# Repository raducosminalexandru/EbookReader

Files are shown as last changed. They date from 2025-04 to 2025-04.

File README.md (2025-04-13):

# OpenBook - E-book Reader Open-Source

In cadrul proiectului **OpenBook**, ne propunem sa revoluționam industria cititului digital prin dezvoltarea unui **e-book reader accesibil, eficient si open-source**. 🌍📚

Cu tehnologia de astazi, accesul la informatie este mai rapid ca niciodata, iar **OpenBook** isi propune sa ofere o solutie accesibila tuturor celor care doresc sa citeasca oriunde, oricand, fara a depinde de preturi exorbitante sau de platforme inchise. Suntem o echipa pasionata si inovativa, iar rolul nostru in acest proiect este sa creem un dispozitiv care sa ofere o experienta de citire excelenta si sa fie disponibil pentru toti utilizatorii, fara bariere. 💡

**OpenBook** este un e-book reader care va permite cititorilor sa acceseze si sa citeasca carti digitale intr-un mod simplu si eficient. Acesta ofera o solutie economica si open-source, ceea ce inseamna ca orice persoana va putea sa-l foloseasca, personalizeze sau imbunatateasca, fara restrictii legate de software sau costuri ridicate.

## Cum functioneaza

Prin utilizarea unor componente hardware eficiente si un software open-source, **OpenBook** va oferi o experienta de citire fluida, cu un design simplu si intuitiv. Acesta va suporta formate de carti populare si va fi usor de utilizat, chiar si pentru utilizatorii care nu sunt familiarizati cu tehnologia.

Prin intermediul acestui dispozitiv, punem bazele unui produs care va oferi cititorilor libertatea de a se bucura de carti digitale intr-un mod accesibil si fara compromisuri in ceea ce priveste performanta si functionalitatea.

## Bill of Materials (BOM) - varianta succinta a fisierului BOM

| Componenta | Link si Datasheet |
|---|---|
| **ESP32-C6-WROOM-1-N8** | [Mouser](https://eu.mouser.com/ProductDetail/Espressif-Systems/ESP32-C6-WROOM-1-N8?qs=8Wlm6%252BaMh8ST02Gmwp74cw%3D%3D) |
| **W25Q512JVEIQ** | [Mouser](https://eu.mouser.com/ProductDetail/Winbond/W25Q512JVEIQ?qs=l7cgNqFNU1jw6svr3at6tA%3D%3D) |
| **DS3231SN#** | [Mouser](https://www.mouser.ro/ProductDetail/100uF-Capacitor](https://eu.mouser.com/ProductDetail/Analog-Devices-Maxim-Integrated/DS3231SN?qs=1eQvB6Dk1vhUlr8%2FOrV0Fw%3D%3D)) |
| **FH34SRJ-24S-0.5SH** | [Mouser](https://www.mouser.ro/ProductDetail/Atmel/ATMEGA328P](https://eu.mouser.com/ProductDetail/Hirose-Connector/FH34SRJ-24S-0.5SH50?qs=iyLo5FA4poC8fzWlavnA7A%3D%3D)) |
| **USB4110-GF-A** | [Mouser](https://www.mouser.ro/ProductDetail/Atmel/ATMEGA328P](https://eu.mouser.com/ProductDetail/Hirose-Connector/FH34SRJ-24S-0.5SH50?qs=iyLo5FA4poC8fzWlavnA7A%3D%3D)](https://eu.mouser.com/ProductDetail/GCT/USB4110-GF-A?qs=KUoIvG%2F9IlYiZvIXQjyJeA%3D%3D)) |
| **BME680** | [Mouser](https://www.mouser.ro/ProductDetail/Atmel/ATMEGA328P](https://eu.mouser.com/ProductDetail/Hirose-Connector/FH34SRJ-24S-0.5SH50?qs=iyLo5FA4poC8fzWlavnA7A%3D%3D)](https://eu.mouser.com/ProductDetail/GCT/USB4110-GF-A?qs=KUoIvG%2F9IlYiZvIXQjyJeA%3D%3D)](https://eu.mouser.com/ProductDetail/Bosch-Sensortec/BME680?qs=v271MhAjFHjo0yA%2FC4OnDQ%3D%3D)) |
| **XC6220A331MR-G** | [Mouser](https://eu.mouser.com/ProductDetail/Torex-Semiconductor/XC6220A331MR-G?qs=AsjdqWjXhJ8ZSWznL1J0gg%3D%3D) |
| **USBLC6-2SC6Y** | [Mouser](https://ro.mouser.com/ProductDetail/STMicroelectronics/USBLC6-2SC6Y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) |
| **BD5229G-TR** | [Mouser](https://ro.mouser.com/ProductDetail/ROHM-Semiconductor/BD5229G-TR?qs=4kLU8WoGk0vvnhrrYwdszw%3D%3D) |
| **MAX17048G+T10** | [Mouser](https://ro.mouser.com/ProductDetail/Analog-Devices-Maxim-Integrated/MAX17048G%2bT10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) |
| **W25Q512JVEIQ** | [Mouser](https://ro.mouser.com/ProductDetail/ROHM-Semiconductor/BD5229G-TR?qs=4kLU8WoGk0vvnhrrYwdszw%3D%3D](https://ro.mouser.com/ProductDetail/Winbond/W25Q512JVEIQ?qs=l7cgNqFNU1jw6svr3at6tA%3D%3D))  
| **Qwiic Right Angle** | [Mouser](https://ro.mouser.com/ProductDetail/Adafruit/4208?qs=PzGy0jfpSMtbScLbr0L5dw%3D%3D) |

Urmatoarea imagine prezinta diagrama bloc de interconectare a componentelor, inclusiv tensiunile de alimentare si protocoalele de comunicatie utilizate intre ele. 🔌📡

<div align="center">

Diagrama

</div>

Modelul 3D al PCB-ului poate fi observat si in imaginea urmatoare, ceea ce permite o analiza detaliata a componentei si a configuratiei acestuia. Acest model ofera o perspectiva clara asupra dimensiunilor, plasarii componentelor si a traseelor de pe placa, ajutand la identificarea posibilelor interferente sau probleme de proiectare.

<div align="center">
  


</div>

Putem vizualiza si traseele mai bine in modelul 3D, ceea ce faciliteaza o analiza mai detaliata a conexiunilor dintre componente. Acest lucru permite identificarea eventualelor probleme legate de lungimea sau latimea traseelor, precum si a eventualelor puncte de coliziune sau interferenta.

<div align="center">
  


</div>

📐 **Integrarea modelului 3D al display-ului si al bateriei**

Pentru o reprezentare cat mai completa a ansamblului final, au fost incluse in proiect si modelele 3D ale display-ului si ale bateriei. Aceasta decizie a avut un rol esential in etapa de validare a designului, permitand o evaluare vizuala si functionala a intregului sistem, direct in mediul 3D.

Prin integrarea acestor componente, a fost posibila:
- ✅ **Verificarea compatibilitatii dimensionale** – Asigurarea ca fiecare componenta are un spatiu adecvat in interiorul carcasei, fara suprapuneri sau conflicte mecanice.
- 🧩 **Optimizarea pozitionarii componentelor** – Plasarea strategica a display-ului si bateriei pentru a facilita accesul, vizibilitatea, distributia greutatii si eficienta termica.
- 🧠 **Identificarea timpurie a potentialelor probleme de spatiu** – Vizualizarea in 3D permite observarea oricaror interferente sau nepotriviri intre PCB, baterie, display si carcasa proiectului.
- 🔧 **Eficientizarea procesului de prototipare** – Un model 3D complet si realist reduce riscul de erori in faza de fabricatie, scurtand ciclurile de testare si ajustare.

Aceasta abordare contribuie direct la cresterea fiabilitatii produsului final, asigurand ca toate componentele nu doar functioneaza impreuna, ci si se potrivesc perfect in structura fizica a dispozitivului.

</div>

<div align="center">
  


</div>

<div align="center">
  


</div>

<div align="center">
  
3D EBOOK

</div>

### Cerinte de 'Good Practice' respectate de dispozitiv:

✅ Traseele de alimentare (VCC, VUSB, VBUS, 3V3 etc.) sunt rutate folosind width = 0.3mm, semnalele de date cu minimum width de 0.15mm.  
✅ Antena modulului ESP32 este amplasata spre exteriorul PCB-ului si PCB-ul trebuie sa fie decupat sub antena.  
✅ Verificare ERC si DRC.  
✅ Condensatoarele de decuplare (100nF) sunt amplasate cat mai aproape de pinii de alimentare ai diferitelor module si circuite integrate.  
✅ Suprafata PCB-ului de sub antena modulului ESP32 a fost decupata pentru a crea cat mai putine interferente cu semnalul radio.  
✅ Planuri de masa situate pe ambele nivele (TOP, BOTTOM).  
✅ Antena modulului ESP32 este amplasata spre exteriorul PCB-ului si PCB-ul este decupat sub antena.  
✅ S-a aplicat 'Via Stitching' intre cele doua planuri de masa, in special in preajma modulului ESP32, precum si in jurul componentelor principale.
✅ Placa are grosimea de 1mm, lucru ce permite introducerea in carcasa si pozitionarea corecta a mufelor.
✅ Vias-uri legate de masa au fost aplicate in toate zonele in care nu se facea 'Pour'.
✅ Valorile rezistentelor si condensatoarelor au fost sterse din 'Board' de pe layer-ul 'Silkscreen' pentru a permite o lizibilitate mai buna.
✅ Footprint-urile anumitor componente au fost schimbate prin modificarea marimilor unor pini, permitand traseele de putere sa se lege la ele, acestea fiind mai groase.
✅ Nu exista unghiuri drepte in cadrul rutarii pe placa.

### Erori acceptate pe dispozitiv:
✅Erorile 'Board Outline Clearance', conform cerintelor impuse.

### 🌐 Surse auxiliare utilizate pentru modele 3D

## Surse externe pentru modelarea 3D a ansamblului

Pentru a completa designul 3D al placii si a asigura o reprezentare cat mai fidela a ansamblului, au fost utilizate urmatoarele surse externe:

🔍 **Component Search Engine**  
Aceasta platforma a fost principalul instrument folosit pentru importarea modelelor 3D ale componentelor electronice standard. A oferit o integrare rapida si precisa cu software-ul de proiectare, facilitand plasarea corecta a componentelor in layout-ul 3D.

🟢 **Farnell**  
Modelele 3D ale butoanelor nu erau disponibile in Component Search Engine, asa ca s-a apelat la biblioteca pusa la dispozitie de Farnell. Aceasta ofera fisiere 3D compatibile si bine detaliate, utile pentru verificarea dimensiunilor fizice si a spatiului ocupat pe placa.

📦 **GrabCAD**  
Modelul 3D al Solder Jumper-ului (SJ) a fost descarcat de pe GrabCAD, o platforma colaborativa care pune la dispozitie o varietate larga de modele CAD. A fost ales un model potrivit, care a fost ulterior ajustat pentru a corespunde dimensiunilor reale folosite in proiect.

# Pinii ESP32 C6 folositi

Se poate vizualiza modul de conectare al componentelor in raport cu ESP32 C6. Se poate observa clar cum acesta poate fi atat 'Master', cat si 'Slave', lucru ce permite comunicatia SPI.

## 1. SD Card
- **CLK** → GPIO6  
- **CMD** → GPIO7  
- **DATA0** → GPIO8  
- **DATA1** → GPIO9  
- **DATA2** → GPIO10  
- **DATA3** → GPIO11  

## 2. Ecran E-Paper
Comunicare prin SPI și GPIO-uri adiționale:
- **MOSI** → GPIO4  
- **SCK** → GPIO5  
- **DC** → GPIO18  
- **CS** → GPIO17  
- **BUSY** → GPIO16  
- **RESET** → GPIO15  

## 3. Memorie NOR Flash 64MB (W25Q512JV)
Comunicare prin SPI:
- **MOSI** → GPIO4  
- **MISO** → GPIO3  
- **CLK** → GPIO5  
- **CS** → GPIO2  

## 4. Senzor de mediu BME688 (I2C)
- **SCL** → GPIO20  
- **SDA** → GPIO19  

## 5. RTC DS3231SN (I2C)
- **SCL** → GPIO20  
- **SDA** → GPIO19  

## 6. Qwiic / Stemma QT (I2C)
- **SCL** → GPIO20  
- **SDA** → GPIO19  

## 7. Indicator nivel baterie (MAX17048G+T10) (I2C)
- **SCL** → GPIO20  
- **SDA** → GPIO19  

## 8. Buton de Reset și Boot
- **Reset** → GPIO0  
- **Boot** → GPIO1

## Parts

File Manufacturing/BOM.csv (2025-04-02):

Qty | Value | Device | Package | Parts | Description | ARROW_PART_NUMBER | ARROW_PRICE-STOCK | AVAILABILITY | CENTROID_NOT_SPECIFIED | CHECK_PRICES | COPYRIGHT | DATASHEET | DESCRIPTION | DIGIKEY_DESCRIPTION | DIGIKEY_PART_NUMBER | HEIGHT | LEAD_FREE | MANUFACTURER_NAME | MANUFACTURER_PART_NUMBER | MF | MFR_NAME | MOUSER_PART_NUMBER | MOUSER_PRICE-STOCK | MOUSER_TESTING_PART_NUMBER | MOUSER_TESTING_PRICE-STOCK | MP | MPN | PACKAGE | POPULARITY | PREFIX | PRICE | PROD_ID | PURCHASE-URL | ROHS | SNAPEDA_LINK | SPICEMODEL | SPICEPREFIX | TEMPERATURE_RANGE_HIGH | TEMPERATURE_RANGE_LOW | TP_SIGNAL_NAME | VALUE
1 |  | ADAFRUIT_LEDCHIP-LED0603 | ADAFRUIT_CHIP-LED0603 | CHG_LED | LED
2 |  | ESP32_WROVER_EAGLE-LTSPICE_CC0402 | ESP32_WROVER_EAGLE-LTSPICE_C0402 | C4_USB, C5_USB | CAPACITOR, European symbol |  |  |  |  |  |  |  |  |  |  |  |  |  |  |  |  |  |  |  |  |  |  |  |  |  |  |  |  |  |  | NONE | C
1 |  | SJ | SJ | SJ1 | SMD solder JUMPER |  |  |  |  |  |  |  |  |  |  |  |  |  |  |  |  |  |  |  |  |  |  |  | 3
1 | 0.1uF/50V | ESP32_WROVER_EAGLE-LTSPICE_CC0402 | ESP32_WROVER_EAGLE-LTSPICE_C0402 | EPD_C5 | CAPACITOR, European symbol |  |  |  |  |  |  |  |  |  |  |  |  |  |  |  |  |  |  |  |  |  |  |  |  |  |  |  |  |  |  | NONE | C
1 | 0.47 | ESP32_WROVER_EAGLE-LTSPICE_RR0402 | ESP32_WROVER_EAGLE-LTSPICE_R0402 | R3 | RESISTOR, European symbol |  |  |  |  |  |  |  |  |  |  |  |  |  |  |  |  |  |  |  |  |  |  |  |  |  |  |  |  |  |  | NONE | R
1 | 100K | ESP32_WROVER_EAGLE-LTSPICE_RR0402 | ESP32_WROVER_EAGLE-LTSPICE_R0402 | R1_PWRUSB | RESISTOR, European symbol |  |  |  |  |  |  |  |  |  |  |  |  |  |  |  |  |  |  |  |  |  |  |  |  |  |  |  |  |  |  | NONE | R
7 | 100nF | ESP32_WROVER_EAGLE-LTSPICE_CC0402 | ESP32_WROVER_EAGLE-LTSPICE_C0402 | C1, C2, C6, C9, C10, C11, C_DELAY | CAPACITOR, European symbol |  |  |  |  |  |  |  |  |  |  |  |  |  |  |  |  |  |  |  |  |  |  |  |  |  |  |  |  |  |  | NONE | C
1 | 100uF | RCL_CPOL-EUCT3528 | RCL_CT3528 | C3 | POLARIZED CAPACITOR, European symbol |  |  |  |  |  |  |  |  |  |  |  |  |  |  |  |  |  |  |  |  |  |  |  | 0 |  |  |  |  |  |  |  | C
16 | 10K | ESP32_WROVER_EAGLE-LTSPICE_RR0402 | ESP32_WROVER_EAGLE-LTSPICE_R0402 | R1, R1-PINH1, R1_PINH, R2-PINH1, R2_PINH, R4, R5, R6, R7, R8, R9, R10, R_BOOT, R_CHANGE, R_CL1, R_RESET | RESISTOR, European symbol |  |  |  |  |  |  |  |  |  |  |  |  |  |  |  |  |  |  |  |  |  |  |  |  |  |  |  |  |  |  | NONE | R
2 | 10uF | ESP32_WROVER_EAGLE-LTSPICE_CC0402 | ESP32_WROVER_EAGLE-LTSPICE_C0402 | C5, C7 | CAPACITOR, European symbol |  |  |  |  |  |  |  |  |  |  |  |  |  |  |  |  |  |  |  |  |  |  |  |  |  |  |  |  |  |  | NONE | C
1 | 112A-TAAR-R03_ATTEND | 112A-TAAR-R03_ATTEND | 112ATAARR03ATTEND | J4 | Micro SD Card Socket, Push-Push Type, Top Mount, SMT, H=1.83mm, 10u |  |  |  |  |  |  |  | Micro SD Card Socket | Push-Push Type | Top Mount | SMT | H=1.83mm | 10u |  |  | 1.9mm |  | ATTEND | 112A-TAAR-R03 ATTEND
1 | 15 | ESP32_WROVER_EAGLE-LTSPICE_RR0402 | ESP32_WROVER_EAGLE-LTSPICE_R0402 | R_CAPACITOR | RESISTOR, European symbol |  |  |  |  |  |  |  |  |  |  |  |  |  |  |  |  |  |  |  |  |  |  |  |  |  |  |  |  |  |  | NONE | R
9 | 1uF/50V | ESP32_WROVER_EAGLE-LTSPICE_CC0402 | ESP32_WROVER_EAGLE-LTSPICE_C0402 | EPD_C1, EPD_C2, EPD_C6, EPD_C7, EPD_C8, EPD_C9, EPD_C10, EPD_C11, EPD_C12 | CAPACITOR, European symbol |  |  |  |  |  |  |  |  |  |  |  |  |  |  |  |  |  |  |  |  |  |  |  |  |  |  |  |  |  |  | NONE | C
1 | 2.2 | ESP32_WROVER_EAGLE-LTSPICE_RR0402 | ESP32_WROVER_EAGLE-LTSPICE_R0402 | R2 | RESISTOR, European symbol |  |  |  |  |  |  |  |  |  |  |  |  |  |  |  |  |  |  |  |  |  |  |  |  |  |  |  |  |  |  | NONE | R
1 | 200 | ESP32_WROVER_EAGLE-LTSPICE_RR0402 | ESP32_WROVER_EAGLE-LTSPICE_R0402 | R1_BAT | RESISTOR, European symbol |  |  |  |  |  |  |  |  |  |  |  |  |  |  |  |  |  |  |  |  |  |  |  |  |  |  |  |  |  |  | NONE | R
2 | 20V/4.2A/52mO/1.4W | ESP32_WROVER_SPARKFUN-DISCRETESEMI_MOSFET_PCH-DMG2305UX-7 | ESP32_WROVER_SPARKFUN-DISCRETESEMI_SOT23-3 | Q1, Q2 | P-channel MOSFETs |  |  |  |  |  |  |  |  |  |  |  |  |  |  |  |  |  |  |  |  |  |  |  |  |  |  | TRAN-14388 |  |  |  |  |  |  |  |  | 20V/4.2A/52mO/1.4W
1 | 2K | ESP32_WROVER_EAGLE-LTSPICE_RR0402 | ESP32_WROVER_EAGLE-LTSPICE_R0402 | R2_BAT | RESISTOR, European symbol |  |  |  |  |  |  |  |  |  |  |  |  |  |  |  |  |  |  |  |  |  |  |  |  |  |  |  |  |  |  | NONE | R
4 | 4.7uF | ESP32_WROVER_EAGLE-LTSPICE_CC0402 | ESP32_WROVER_EAGLE-LTSPICE_C0402 | C1_BAT, C1_BAT1, C1_BAT2, C2_BAT | CAPACITOR, European symbol |  |  |  |  |  |  |  |  |  |  |  |  |  |  |  |  |  |  |  |  |  |  |  |  |  |  |  |  |  |  | NONE | C
1 | 4.7uF/25V | ESP32_WROVER_EAGLE-LTSPICE_CC0402 | ESP32_WROVER_EAGLE-LTSPICE_C0402 | C4 | CAPACITOR, European symbol |  |  |  |  |  |  |  |  |  |  |  |  |  |  |  |  |  |  |  |  |  |  |  |  |  |  |  |  |  |  | NONE | C
2 | 5k1 | ESP32_WROVER_EAGLE-LTSPICE_RR0402 | ESP32_WROVER_EAGLE-LTSPICE_R0402 | R2-USB, R2-USB1 | RESISTOR, European symbol |  |  |  |  |  |  |  |  |  |  |  |  |  |  |  |  |  |  |  |  |  |  |  |  |  |  |  |  |  |  | NONE | R
1 | 68uH | 744043680IND_4828-WE-TPC_WRE | IND_4828-WE-TPC_WRE | L1 |  |  |  |  |  |  | Copyright (C) 2024 Ultra Librarian. All rights reserved. |  |  |  |  |  |  |  | 744043680 |  | Wurth Electronics
1 | BD5229G-TR | BD5229G-TR | SOT95P280X125-5N | IC1 | Voltage Detector with Adjustable Delay Time: CMOS processes are utilized to develop high precision, low current consumption CMOS reset ICs that allow arbitrary setting of the delay time. The extensive lineup includes both Nch Open Drain and CMOS output types in a wide range of detection voltages (from 2.3V to 6.0V, in 0.1V steps), enabling selection of the ideal solution based on customer requirements. In addition, the entire series is of course both lead-free and RoHS-compliant. |  |  |  |  |  |  |  | Voltage Detector with Adjustable Delay Time: CMOS processes are utilized to develop high precision | low current consumption CMOS reset ICs that allow arbitrary setting of the delay time. The extensive lineup includes both Nch Open Drain and CMOS output types in a wide range of detection voltages (from 2.3V to 6.0V | in 0.1V steps) | enabling selection of the ideal solution based on customer requirements. In addition | the entire series is of course both lead-free and RoHS-compliant. |  |  | 1.25mm |  | ROHM Semiconductor | BD5229G-TR |  |  | 755-BD5229G-TR | https://www.mouser.co.uk/ProductDetail/ROHM-Semiconductor/BD5229G-TR?qs=4kLU8WoGk0vvnhrrYwdszw%3D%3D
3 | BUTTON_CUSYOMV1 | BUTTON_CUSYOMV1 | MYBUTTON | BOOT_BUTTON, CHANGE_BUTTON, RESET_BUTTON
1 | CPH3225A | CPH3225A | CAPCP3225X100N | C10_SUPERCAP | Cap 0.011F 3.3V 1210 Flat Check availability |  |  | Not in stock |  | https://www.snapeda.com/parts/CPH3225A/Seiko+Instruments/view-part/?ref=eda |  |  | 11 mF (EDLC) Supercapacitor 3.3 V 1210 (3225 Metric) - - |  |  |  |  |  |  | Seiko Instruments |  |  |  |  |  | CPH3225A |  | 1210 Seiko |  |  | None |  | https://www.snapeda.com/api/url_track_click_mouser/?unipart_id=562593&manufacturer=Seiko Instruments&part_name=CPH3225A&search_term=None |  | https://www.snapeda.com/parts/CPH3225A/Seiko+Instruments/view-part/?ref=snap
1 | DS3231SN# | DS3231SN# | SOIC127P1032X265-16N | U3 | Real Time Clock Serial 16-Pin SOIC W T/R Check availability |  |  | In Stock |  | https://www.snapeda.com/parts/DS3231SN%23/Analog+Devices/view-part/?ref=eda |  |  | Extremely Accurate I²C-Integrated RTC/TCXO/Crystal |  |  |  |  |  |  | Analog Devices |  |  |  |  |  | DS3231SN# |  | SOIC-16 Maxim |  |  | None |  | https://www.snapeda.com/api/url_track_click_mouser/?unipart_id=99048&manufacturer=Analog Devices&part_name=DS3231SN#&search_term=None |  | https://www.snapeda.com/parts/DS3231SN%23/Analog+Devices/view-part/?ref=snap
1 | ESP32-C6-WROOM-1-N8 | ESP32-C6-WROOM-1-N8 | XCVR_ESP32-C6-WROOM-1-N8 | U2 | Check availability |  |  | In Stock |  | https://www.snapeda.com/parts/ESP32-C6-WROOM-1-N8/Espressif+Systems/view-part/?ref=eda |  |  | Multiprotocol Modules ESP32-C6 module | Wi-Fi 6 in 2.4 GHz band | Bluetooth 5 | Zigbee 3.0 and Thread. ESP34-WROOM Compatible - ENGINEERING SAMPLE |  |  |  |  |  |  | Espressif Systems |  |  |  |  |  | ESP32-C6-WROOM-1-N8 |  | None |  |  | None |  |  |  | https://www.snapeda.com/parts/ESP32-C6-WROOM-1-N8/Espressif+Systems/view-part/?ref=snap
1 | ESP32C6_VARISTORCN1812 | ESP32C6_VARISTORCN1812 | ESP32C6_VARISTOR_CT/CN1812 | PFMF.050.1 | VARISTOR |  |  |  |  |  |  |  |  |  |  |  |  |  |  |  |  |  |  |  |  |  |  |  | 0
2 | ESP32_WROVER_AVX---SD0805S020S1R0_AVX_SD0805S020S1R0_0_0AVX_SD0805S020S1R0_0_0 | ESP32_WROVER_AVX---SD0805S020S1R0_AVX_SD0805S020S1R0_0_0AVX_SD0805S020S1R0_0_0 | ESP32_WROVER_AVX---SD0805S020S1R0_AVX_SD0805S020S1R0_0 | D2, D7 | Schottky Barrier Rectifier Diode |  |  |  | No |  |  | http://datasheets.avx.com/schottky.pdf |  | DIODE SCHOTTKY 20V 1A 0805 | 478-7800-1-ND |  | yes |  |  | AVX |  | 581-SD0805S020S1R0 |  |  |  |  |  | 0805 (2012 metric) |  | D |  |  |  | yes |  |  |  | +125°C | -55°C
1 | ESP32_WROVER_BME680_BME680 | ESP32_WROVER_BME680_BME680 | ESP32_WROVER_BME680_PSON80P300X300X100-8N | SENSOR2 | Integrated Environmental Unit |  |  | Unavailable |  |  |  |  | Integrated Environmental Unit |  |  |  |  |  |  | Bosch Sensortec |  |  |  |  |  | BME680 |  | LGA-8 Bosch Tools |  |  | None
1 | ESP32_WROVER_SPARKFUN-IC-POWER_MCP73831 | ESP32_WROVER_SPARKFUN-IC-POWER_MCP73831 | ESP32_WROVER_SPARKFUN-IC-POWER_SOT23-5 | MCP73831 | MCP73831T Li-Ion, Li-Pol Controller |  |  |  |  |  |  |  |  |  |  |  |  |  |  |  |  |  |  |  |  |  |  |  |  |  |  | IC-09995
1 | FH34SRJ-24S-0.5SH_99_ | FH34SRJ-24S-0.5SH_99_ | FH34SRJ24S05SH99 | J1 | (0.50mm) Surface Mount, Right Angle |  |  |  |  |  |  |  | 24 Position FFC | FPC Connector Contacts | (0.50mm) Surface Mount | Right Angle |  |  | 1.1mm |  | Hirose | FH34SRJ-24S-0.5SH(99) |  |  | 798-FH34SRJ24S05SH99 | https://www.mouser.co.uk/ProductDetail/Hirose-Connector/FH34SRJ-24S-0.5SH99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
1 | MAX17048G+T10 | MAX17048G+T10 | SON50P200X200X80-9N | U4 | Check availability |  |  | In Stock |  | https://www.snapeda.com/parts/MAX17048G+T10/Analog+Devices/view-part/?ref=eda |  |  | 3µA 1-Cell/2-Cell Fuel Gauge with ModelGauge |  |  |  |  |  |  | Analog Devices |  |  |  |  |  | MAX17048G+T10 |  | TDFN-8 Maxim |  |  | None |  | https://www.snapeda.com/api/url_track_click_mouser/?unipart_id=329239&manufacturer=Analog Devices&part_name=MAX17048G+T10&search_term=None |  | https://www.snapeda.com/parts/MAX17048G+T10/Analog+Devices/view-part/?ref=snap
3 | MBR0530 | MBR0530 | SOD3716X135N | D3, D4, D5 | ON SEMICONDUCTOR - MBR0530 - DIODE, SCHOTTKY, 0.5A, 30V, SOD-123 |  |  | In Stock |  | https://www.snapeda.com/parts/MBR0530/Onsemi/view-part/?ref=eda |  |  | Diode Schottky 30 V 500mA Surface Mount SOD-123 |  |  |  |  |  |  | ON Semiconductor |  |  |  |  |  | MBR0530 |  | SOD-123-2 ON Semiconductor |  |  | None |  | https://www.snapeda.com/api/url_track_click_mouser/?unipart_id=179458&manufacturer=ON Semiconductor&part_name=MBR0530&search_term=None |  | https://www.snapeda.com/parts/MBR0530/Onsemi/view-part/?ref=snap
6 | PGB1010603MR | PGB1010603MR | DIOC1608X36N | D6, D8, D9, D10, D11, D12 | Check availability |  |  | In Stock |  | https://www.snapeda.com/parts/PGB1010603MR/Littelfuse/view-part/?ref=eda |  |  | 150V (Typ) Clamp - Ipp Tvs Diode Surface Mount 0603 (1608 Metric) |  |  |  |  |  |  | Littelfuse Inc. |  |  |  |  |  | PGB1010603MR |  | 0603 Littelfuse Inc. |  |  | None |  | https://www.snapeda.com/api/url_track_click_mouser/?unipart_id=5659453&manufacturer=Littelfuse Inc.&part_name=PGB1010603MR&search_term=None |  | https://www.snapeda.com/parts/PGB1010603MR/Littelfuse/view-part/?ref=snap
1 | QWIIC_RIGHT_ANGLE | QWIIC_CONNECTORJS-1MM | JST04_1MM_RA | J3 | SparkFun I2C Standard Qwiic Connector |  |  |  |  |  |  |  |  |  |  |  |  |  |  |  |  |  |  |  |  |  |  |  |  |  |  | CONN-13694 |  |  |  |  |  |  |  |  | QWIIC_RIGHT_ANGLE
1 | SAMACSYS_PARTS_USB4110-GF-A | SAMACSYS_PARTS_USB4110-GF-A | SAMACSYS_PARTS_USB4110GFA | J2 | CONN USB 2.0 TYPE-C R/A SMT |  |  |  |  |  |  |  | CONN USB 2.0 TYPE-C R/A SMT |  |  | 3.26mm |  | GCT (GLOBAL CONNECTOR TECHNOLOGY) | USB4110-GF-A |  |  | 640-USB4110-GF-A | https://www.mouser.co.uk/ProductDetail/GCT/USB4110-GF-A?qs=KUoIvG%2F9IlYiZvIXQjyJeA%3D%3D
1 | SI1308EDL-T1-GE3 | SI1308EDL-T1-GE3 | SOT65P210X110-3N | Q3 | MOSFET N-Ch 30V 1.5A TrenchFET SC70 Vishay Si1308EDL-T1-GE3 N-channel MOSFET Transistor, 1.5 A, 30 V, 3-Pin SC-70 |  |  | In Stock |  | https://www.snapeda.com/parts/SI1308EDL-T1-GE3/Vishay+Siliconix/view-part/?ref=eda |  |  | Si1308EDL-T1-GE3 N-channel MOSFET Transistor | 1.5 A | 30 V | 3-Pin SC-70 | Siliconix / Vishay SI1308EDL-T1-GE3 |  |  |  |  |  |  | Vishay Siliconix |  |  |  |  |  | SI1308EDL-T1-GE3 |  | SOT-323 Vishay Semiconductor |  |  | None |  | https://www.snapeda.com/api/url_track_click_mouser/?unipart_id=274603&manufacturer=Vishay Siliconix&part_name=SI1308EDL-T1-GE3&search_term=None |  | https://www.snapeda.com/parts/SI1308EDL-T1-GE3/Vishay+Siliconix/view-part/?ref=snap
17 | TPTP20R | TPTP20R | TP20R | TP1, TP2, TP3, TP4, TP5, TP6, TP7, TP8, TP9, TP10, TP11, TP12, TP13, TP14, TP15, TP16, TP17 | Test pad |  |  |  |  |  |  |  |  |  |  |  |  |  |  |  |  |  |  |  |  |  |  |  | 2
1 | USBLC6-2SC6Y | USBLC6-2SC6Y | SOT95P280X145-6N | D1 | Low Cap. ESD Protection Auto SOT-23-6 STMicroelectronics USBLC6-2SC6Y, Dual Uni-Directional TVS Diode Array, 6-Pin SOT-23 |  |  | In Stock |  | https://www.snapeda.com/parts/USBLC6-2SC6Y/STMicroelectronics/view-part/?ref=eda |  |  | 17V Clamp 5A (8/20µs) Ipp Tvs Diode Surface Mount SOT-23-6 |  |  |  |  |  |  | STMicroelectronics |  |  |  |  |  | USBLC6-2SC6Y |  | SOT-23-6 STMicroelectronics |  |  | None |  |  |  | https://www.snapeda.com/parts/USBLC6-2SC6Y/STMicroelectronics/view-part/?ref=snap
1 | W25Q512JVEIQ | W25Q512JVEIQ | SON127P600X800X80-9N | U1 | Check availability |  |  | In Stock |  | https://www.snapeda.com/parts/W25Q512JVEIQ/Winbond+Electronics/view-part/?ref=eda |  |  | FLASH - NOR Memory IC 512Mb (64M x 8) SPI - Quad I/O 133 MHz 8-WSON (8x6) |  |  |  |  |  |  | Winbond Electronics |  |  |  |  |  | W25Q512JVEIQ |  | Package |  |  | None |  |  |  | https://www.snapeda.com/parts/W25Q512JVEIQ/Winbond+Electronics/view-part/?ref=snap
1 | XC6220A331MR-G | XC6220A331MR-G | SOT95P280X120-5N | IC4 | LDO Voltage Regulators |  |  |  |  |  |  |  | LDO Voltage Regulators |  |  | 1.2mm |  | Torex | XC6220A331MR-G |  |  | 865-XC6220A331MR-G | https://www.mouser.co.uk/ProductDetail/Torex-Semiconductor/XC6220A331MR-G?qs=AsjdqWjXhJ8ZSWznL1J0gg%3D%3D

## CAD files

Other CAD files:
Mechanical/EbookReader PCB 3D.step
Mechanical/OpenBook Enclosure.step

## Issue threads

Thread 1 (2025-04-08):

Diagrama bloc

mariapana, 2025-04-08:
Pentru a putea vedea mai usor conexiunile comune intre componente, ar fi recomandat ca:
* din chenarul pentru ESP32 sa porneasca o singura linie per tip de conexiune, care apoi sa se ramifice pentru fiecare componenta in parte
* in loc de linii drepte trasate pe diagonala sa folosesti Elbow Connector

Vezi [modelul de schema bloc](https://docs.google.com/drawings/d/1UpxRyJNfczJHhNRvWdeb5kh_7IEUy5173odk93W_GSA/edit) dat in enunt pentru a vedea mai detaliat organizarea schemei.

raducosminalexandru, 2025-04-11:
Am rezolvat, diagrama a fost facuta conform modelului pus la dispozitie in cadrul cerintei de proiect (am folosit Elbow Connector pentru lizibilitate).

Closed 2025-04-11.

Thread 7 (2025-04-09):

DRC - Component Exclude Clearance

mariapana, 2025-04-09:
Unele componente sunt prea apropiate pe PCB, producand eroarea `Component Exclude Clearance` la DRC. Este suficient sa distantezi `EPD_C12` de `EPD_C10`.

raducosminalexandru, 2025-04-13:
Am rezolvat, am repozitionat componentele ce creeau problema.

Closed 2025-04-13.

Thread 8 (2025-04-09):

DRC - Air Wire

mariapana, 2025-04-09:
Conform verificarii DRC, exista mai multe erori de tip Air Wire din cauza unor trasee nerutate. Incearca sa minimizezi numarul lor folosind Autorouter sau realizand trasarea manual.

raducosminalexandru, 2025-04-13:
Am rezolvat, toti pinii de ground au fost rutati la masa cu ajutorul via-urilor legate la GND.

Closed 2025-04-13.

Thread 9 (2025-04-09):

DRC - Board Outline Clearance

mariapana, 2025-04-09:
Conform verificarii DRC, exista mai multe erori "Board Outline Clearance".
Acestea apar din cauza pozitionarii butoanelor.
Remediaza erorile mutand butoanele mai aproape de interiorul PCB-ului (astfel incat "baza" butonului sa fie pe PCB si doar butonul efectiv sa iasa in exterior).

raducosminalexandru, 2025-04-13:
Am rezolvat, butoanele au fost repozitionate.

Closed 2025-04-13.

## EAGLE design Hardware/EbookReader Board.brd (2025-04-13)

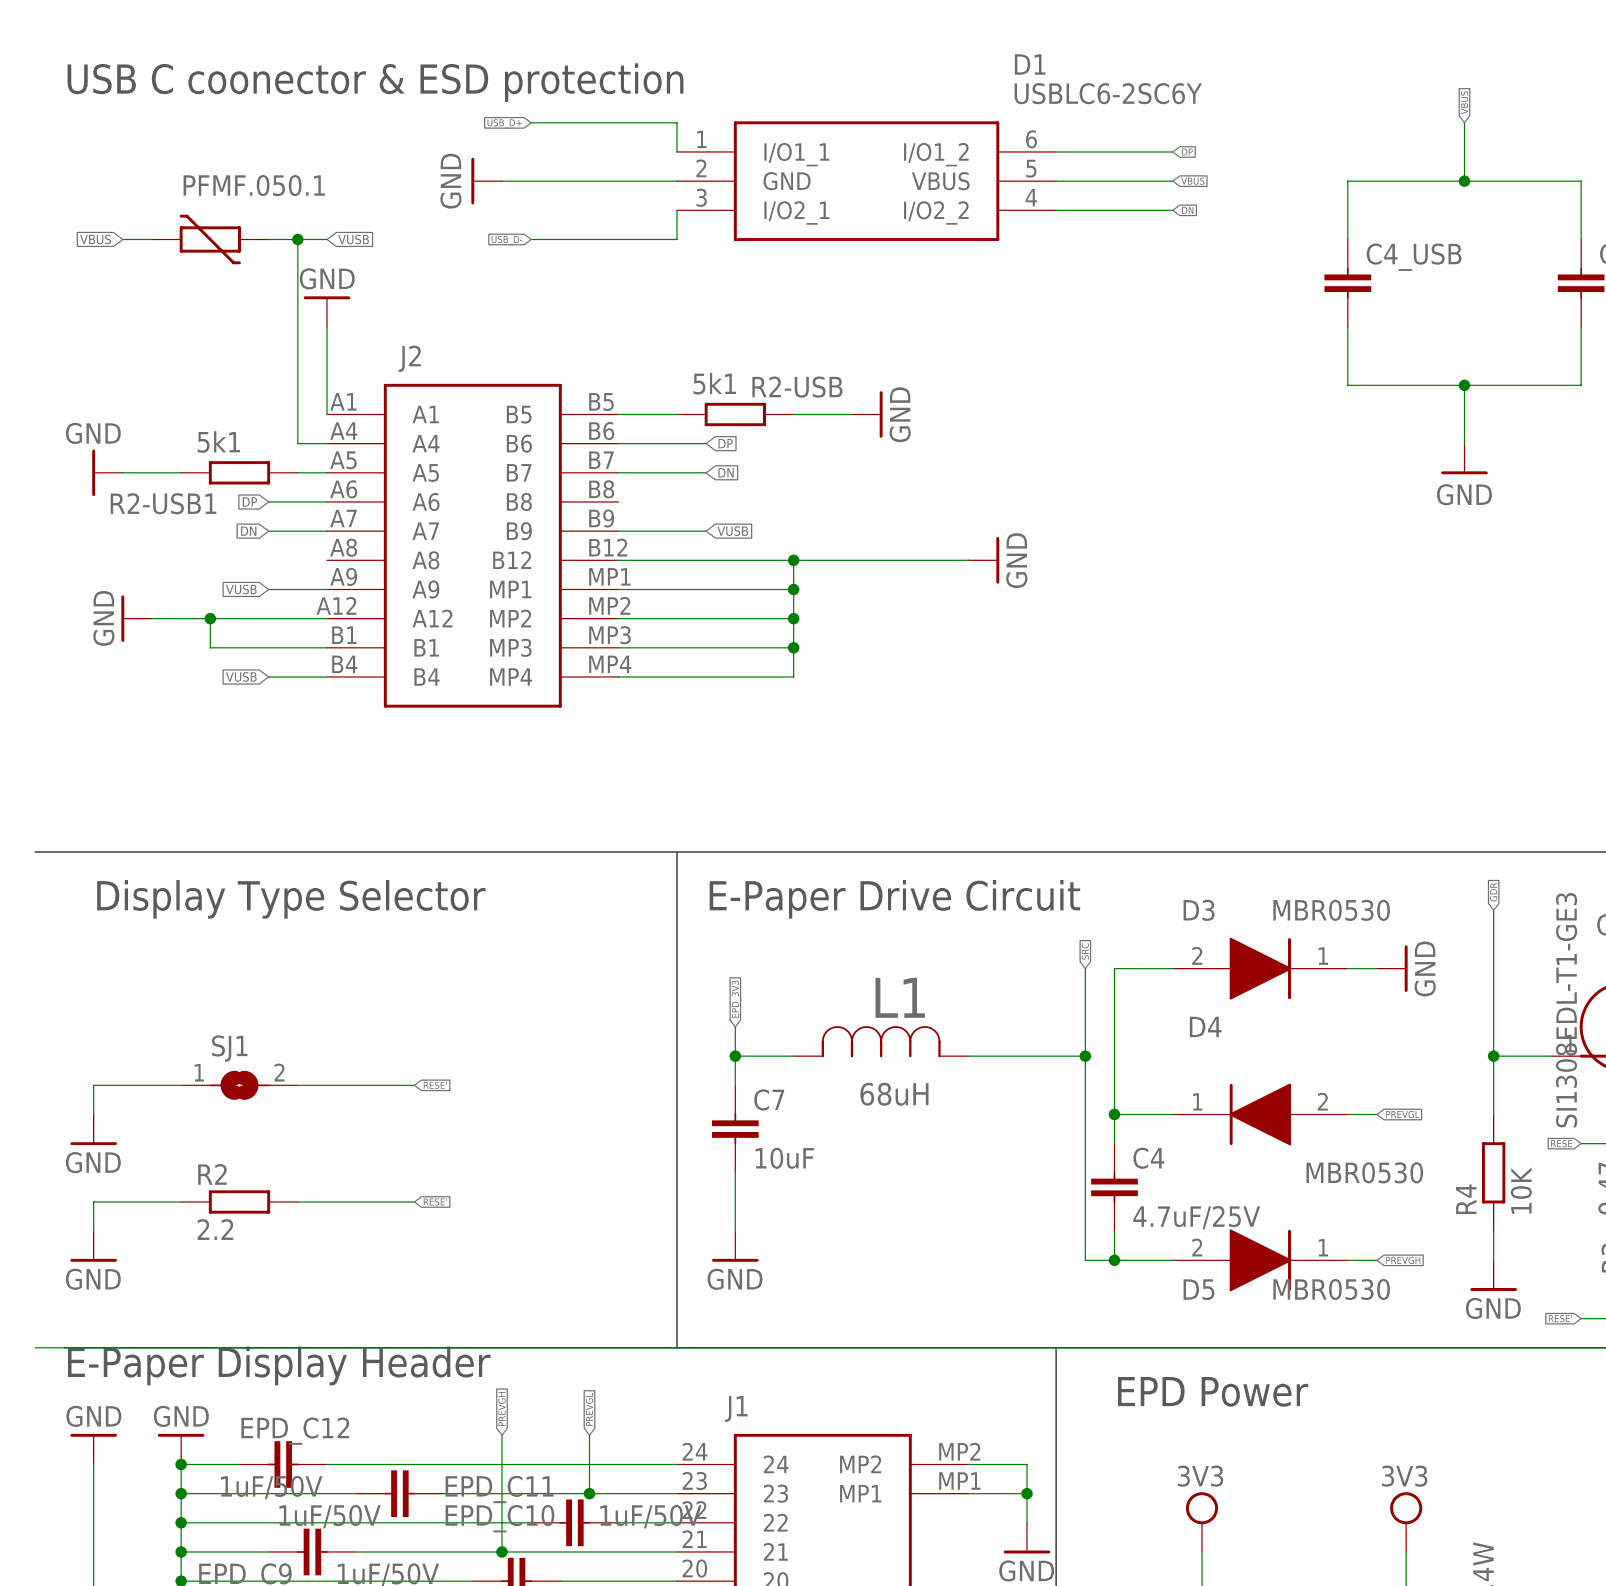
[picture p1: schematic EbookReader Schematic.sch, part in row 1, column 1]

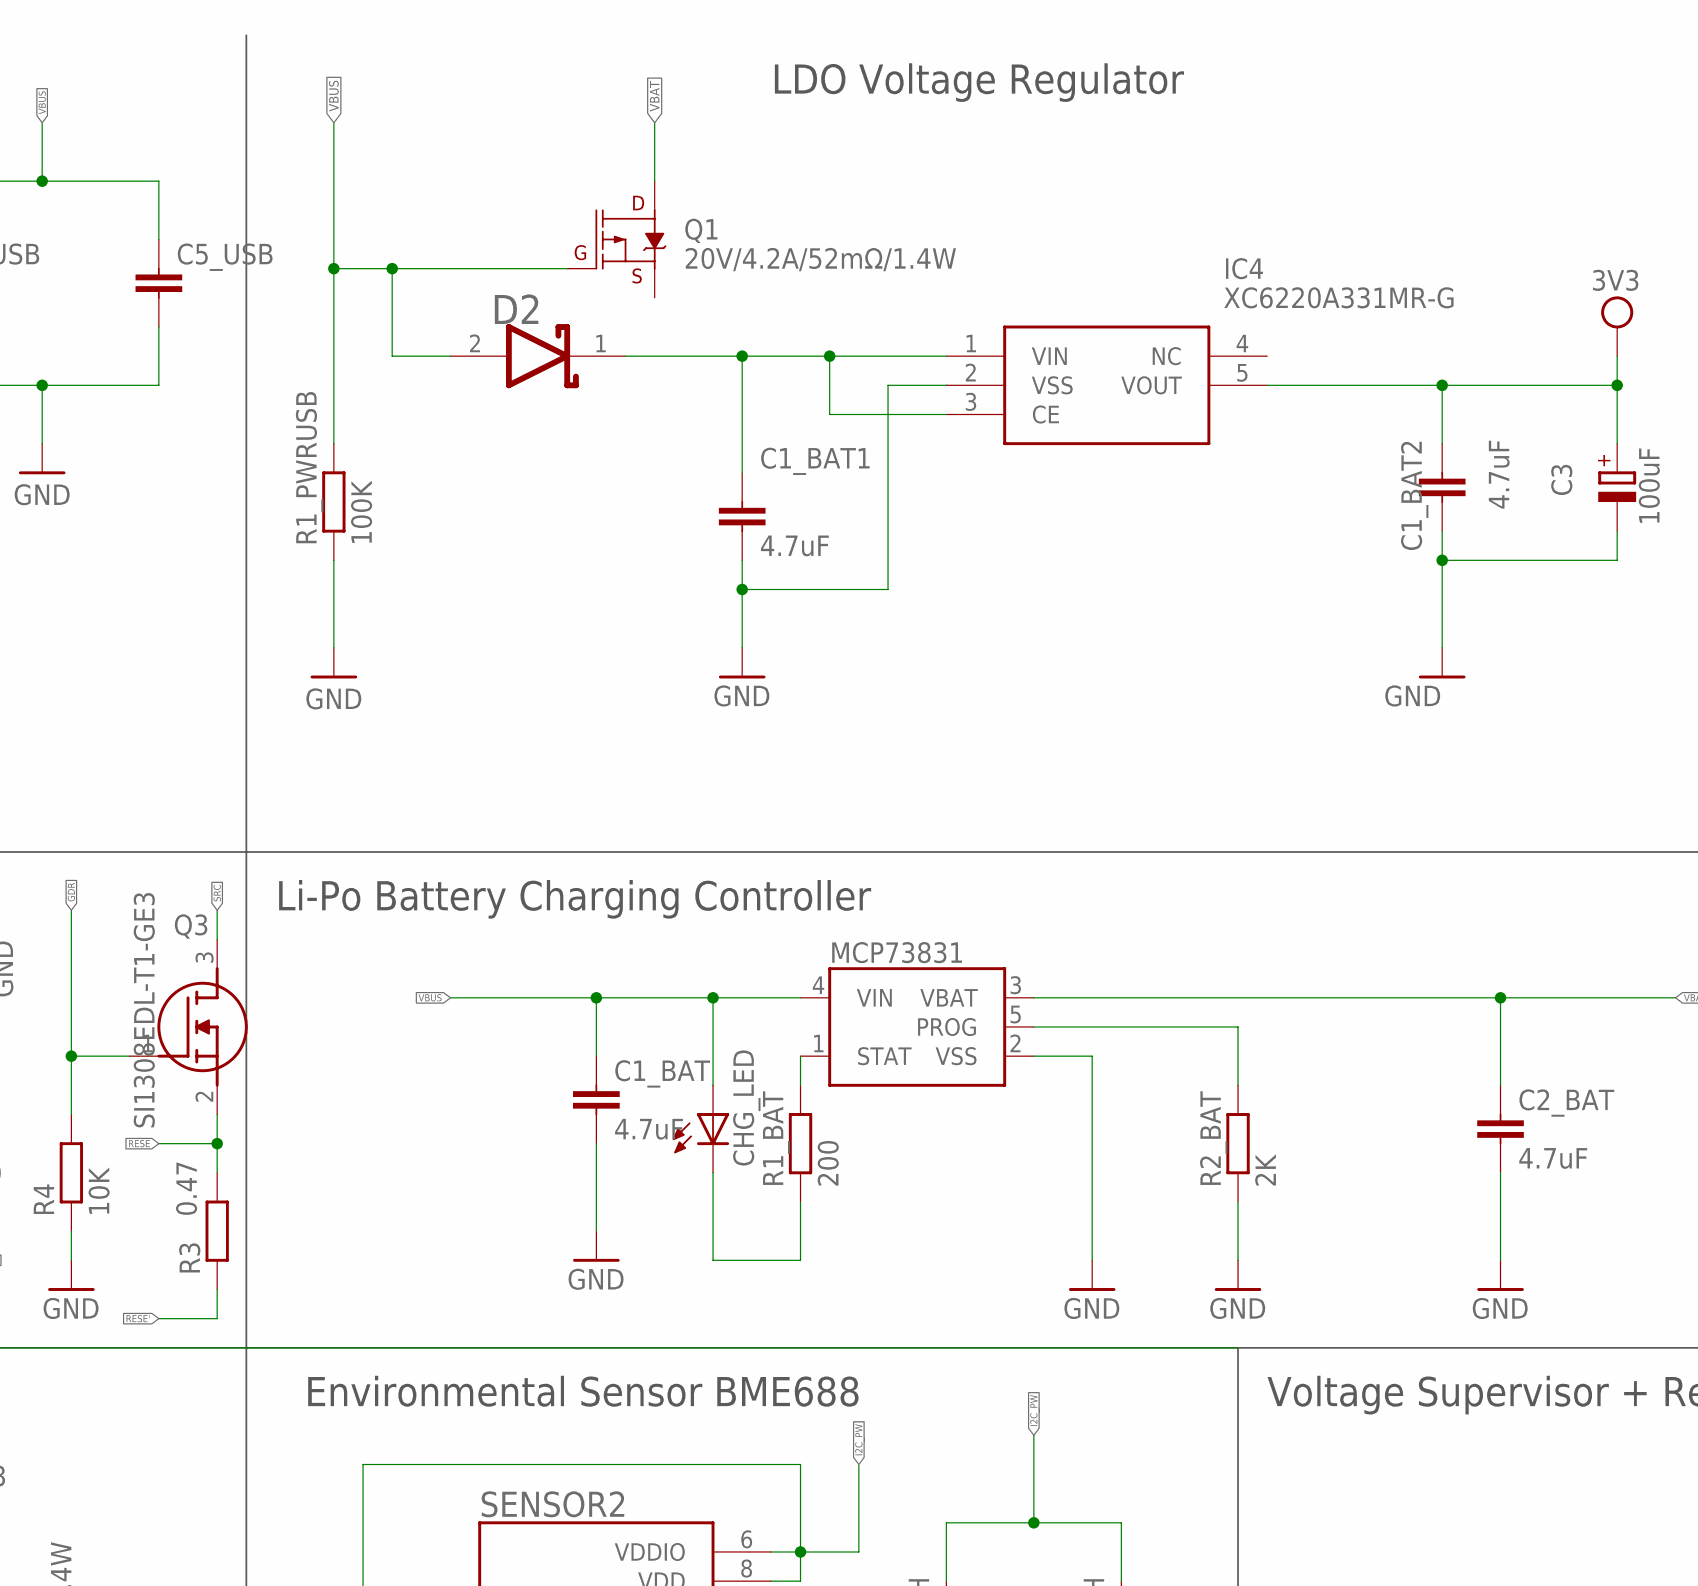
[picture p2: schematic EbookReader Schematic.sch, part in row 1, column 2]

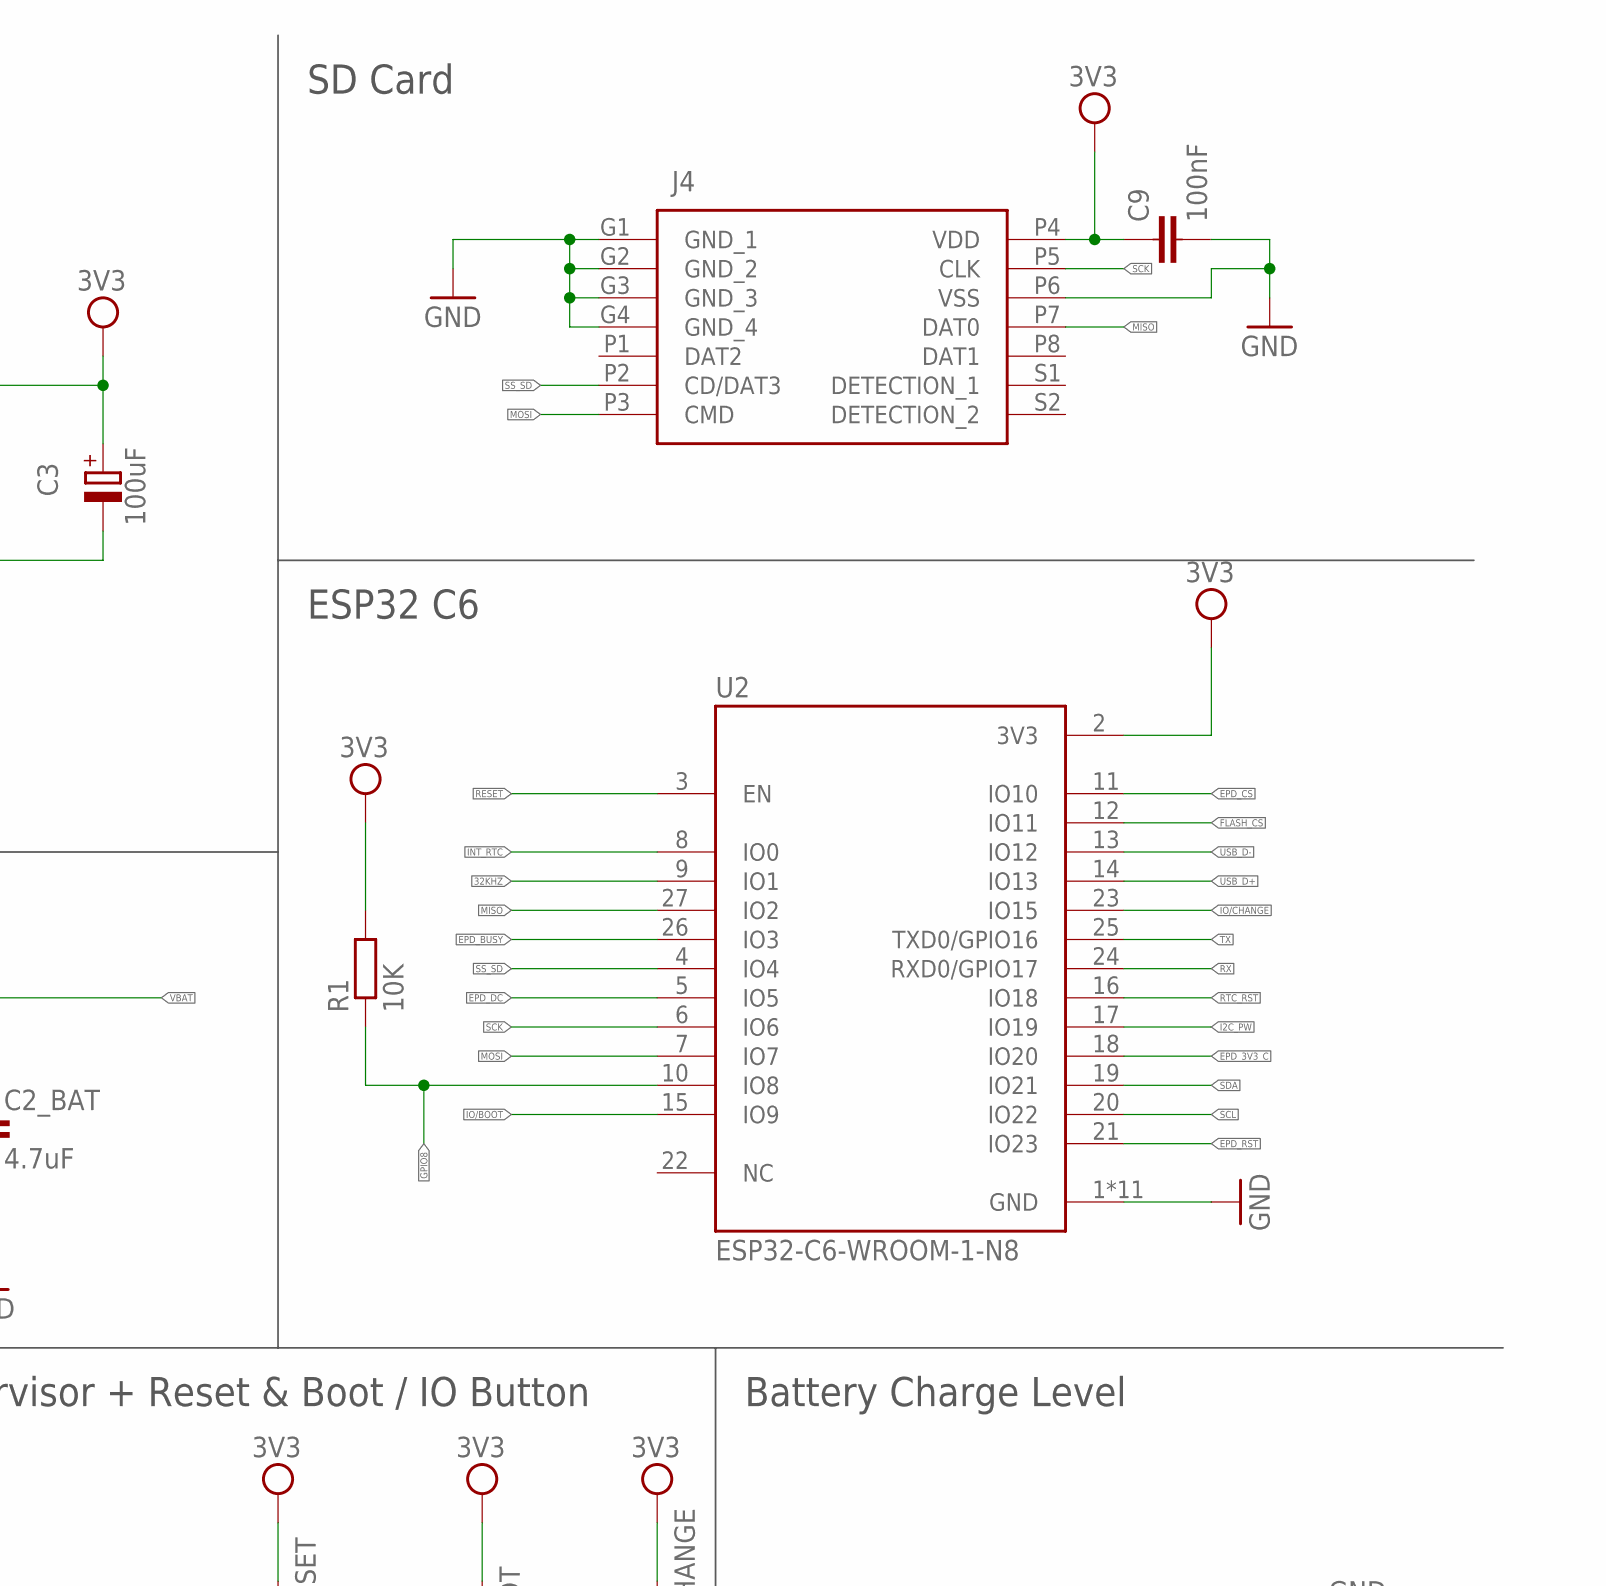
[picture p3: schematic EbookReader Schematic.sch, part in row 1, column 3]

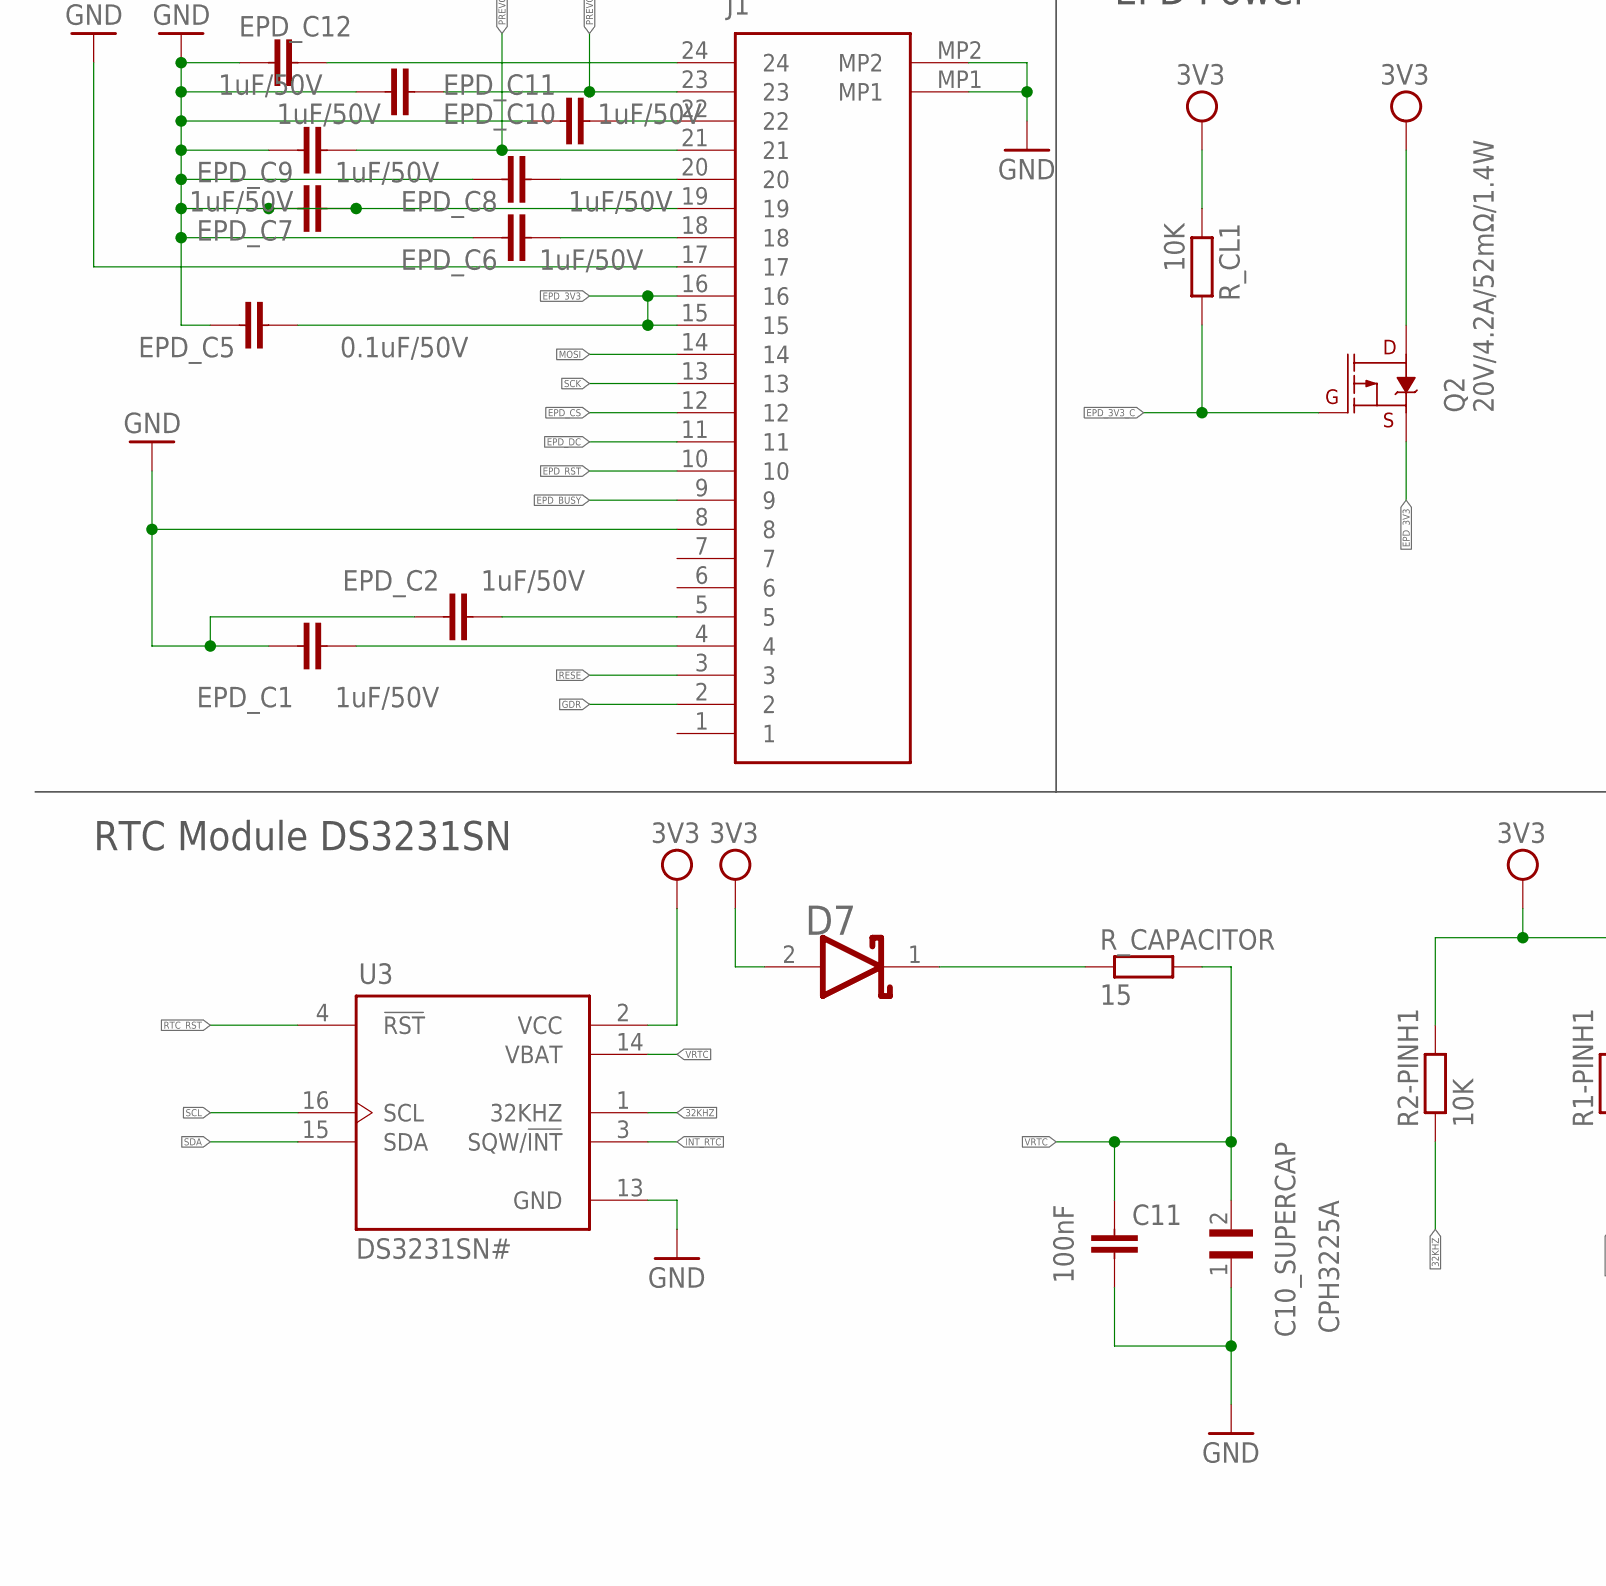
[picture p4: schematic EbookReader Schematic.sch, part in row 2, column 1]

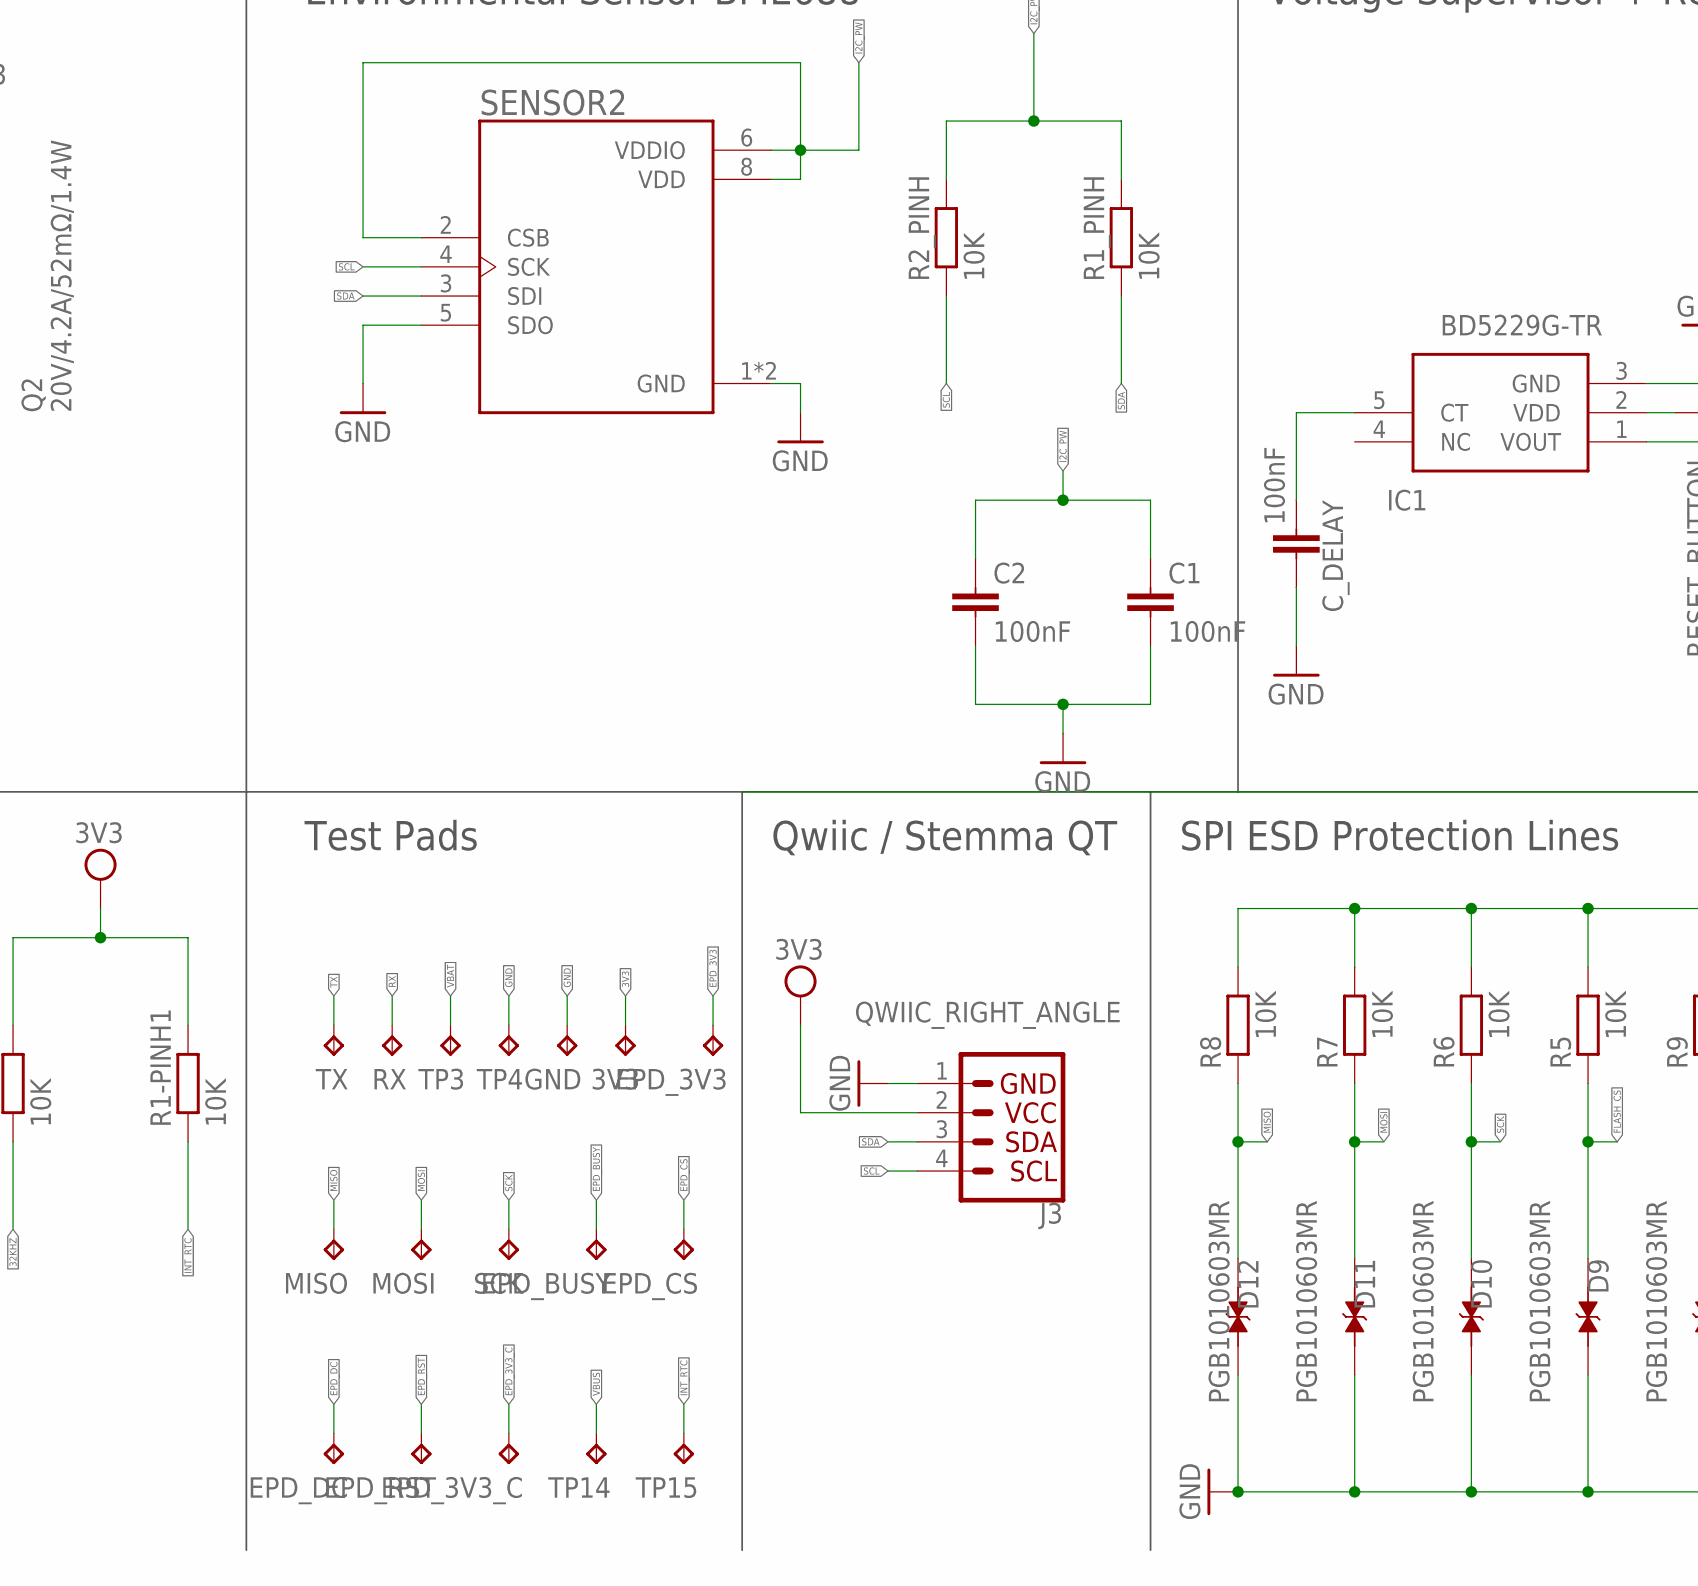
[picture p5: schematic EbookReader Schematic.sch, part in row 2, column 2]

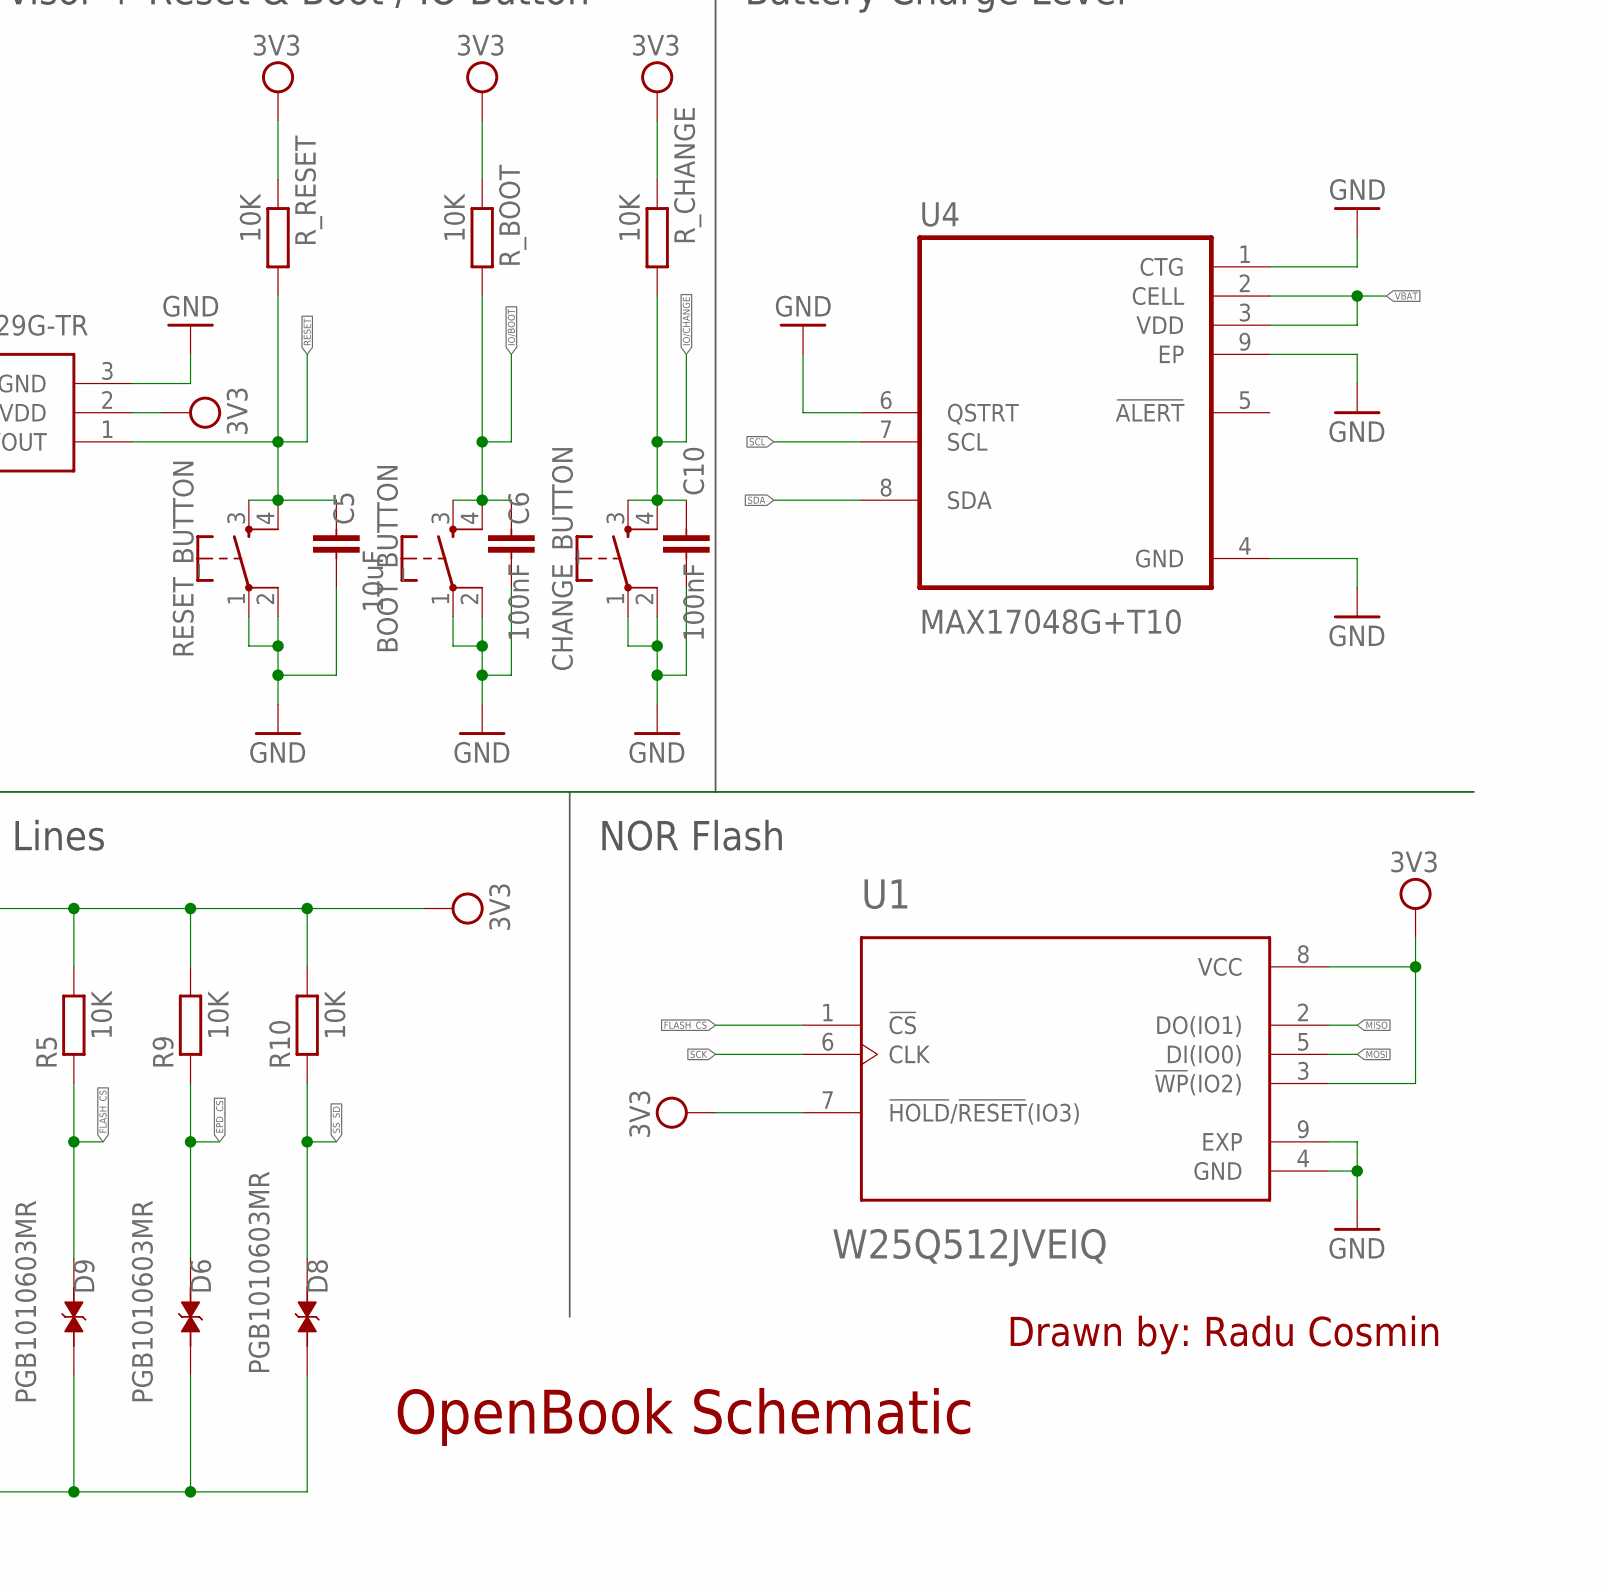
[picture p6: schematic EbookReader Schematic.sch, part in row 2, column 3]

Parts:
3V3: TPTP20R; TP20R
BOOT_BUTTON: BUTTON_CUSYOMV1; MYBUTTON
C1, C2, C6, C9, C10, C11: 100nF; ESP32_WROVER_EAGLE-LTSPICE_C0402
C1_BAT, C1_BAT1, C1_BAT2, C2_BAT: 4.7uF; ESP32_WROVER_EAGLE-LTSPICE_C0402
C3: 100uF; RCL_CT3528
C4: 4.7uF/25V; ESP32_WROVER_EAGLE-LTSPICE_C0402
C4_USB, C5_USB: ESP32_WROVER_EAGLE-LTSPICE_CC0402; ESP32_WROVER_EAGLE-LTSPICE_C0402
C5, C7: 10uF; ESP32_WROVER_EAGLE-LTSPICE_C0402
C10_SUPERCAP: CPH3225A; CAPCP3225X100N
CHANGE_BUTTON: BUTTON_CUSYOMV1; MYBUTTON
CHG_LED: ADAFRUIT_LEDCHIP-LED0603; ADAFRUIT_CHIP-LED0603
C_DELAY: 100nF; ESP32_WROVER_EAGLE-LTSPICE_C0402
D1: USBLC6-2SC6Y; SOT95P280X145-6N
D2, D7: ESP32_WROVER_AVX---SD0805S020S1R0_AVX_SD0805S020S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; ESP32_WROVER_AVX---SD0805S020S1R0_AVX_SD0805S020S1R0_0
D3, D4, D5: MBR0530; SOD3716X135N
D6, D8, D9, D10, D11, D12: PGB1010603MR; DIOC1608X36N
EPD_3V3, EPD_3V3_C: TPTP20R; TP20R
EPD_BUSY: TPTP20R; TP20R
EPD_C1, EPD_C2, EPD_C6, EPD_C7, EPD_C8, EPD_C9, EPD_C10, EPD_C11, EPD_C12: 1uF/50V; ESP32_WROVER_EAGLE-LTSPICE_C0402
EPD_C5: 0.1uF/50V; ESP32_WROVER_EAGLE-LTSPICE_C0402
EPD_CS: TPTP20R; TP20R
EPD_DC: TPTP20R; TP20R
EPD_RST: TPTP20R; TP20R
GND: TPTP20R; TP20R
IC1: BD5229G-TR; SOT95P280X125-5N
IC4: XC6220A331MR-G; SOT95P280X120-5N
J1: FH34SRJ-24S-0.5SH_99_; FH34SRJ24S05SH99
J2: SAMACSYS_PARTS_USB4110-GF-A; SAMACSYS_PARTS_USB4110GFA
J3: QWIIC_RIGHT_ANGLE; JST04_1MM_RA
J4: 112A-TAAR-R03_ATTEND; 112ATAARR03ATTEND
L1: 68uH; IND_4828-WE-TPC_WRE
MCP73831: ESP32_WROVER_SPARKFUN-IC-POWER_MCP73831; ESP32_WROVER_SPARKFUN-IC-POWER_SOT23-5
MISO: TPTP20R; TP20R
MOSI: TPTP20R; TP20R
PFMF.050.1: ESP32C6_VARISTORCN1812; ESP32C6_VARISTOR_CT/CN1812
Q1, Q2: 20V/4.2A/52mΩ/1.4W; ESP32_WROVER_SPARKFUN-DISCRETESEMI_SOT23-3
Q3: SI1308EDL-T1-GE3; SOT65P210X110-3N
R1, R1-PINH1, R1_PINH, R2-PINH1, R2_PINH, R4, R5, R6, R7, R8, R9, R10: 10K; ESP32_WROVER_EAGLE-LTSPICE_R0402
R1_BAT: 200; ESP32_WROVER_EAGLE-LTSPICE_R0402
R1_PWRUSB: 100K; ESP32_WROVER_EAGLE-LTSPICE_R0402
R2: 2.2; ESP32_WROVER_EAGLE-LTSPICE_R0402
R2-USB, R2-USB1: 5k1; ESP32_WROVER_EAGLE-LTSPICE_R0402
R2_BAT: 2K; ESP32_WROVER_EAGLE-LTSPICE_R0402
R3: 0.47; ESP32_WROVER_EAGLE-LTSPICE_R0402
RESET_BUTTON: BUTTON_CUSYOMV1; MYBUTTON
RX: TPTP20R; TP20R
R_BOOT: 10K; ESP32_WROVER_EAGLE-LTSPICE_R0402
R_CAPACITOR: 15; ESP32_WROVER_EAGLE-LTSPICE_R0402
R_CHANGE: 10K; ESP32_WROVER_EAGLE-LTSPICE_R0402
R_CL1: 10K; ESP32_WROVER_EAGLE-LTSPICE_R0402
R_RESET: 10K; ESP32_WROVER_EAGLE-LTSPICE_R0402
SCK: TPTP20R; TP20R
SENSOR2: ESP32_WROVER_BME680_BME680; ESP32_WROVER_BME680_PSON80P300X300X100-8N
SJ1: SJ
TP3, TP4, TP14, TP15: TPTP20R; TP20R
TX: TPTP20R; TP20R
U1: W25Q512JVEIQ; SON127P600X800X80-9N
U2: ESP32-C6-WROOM-1-N8; XCVR_ESP32-C6-WROOM-1-N8
U3: DS3231SN#; SOIC127P1032X265-16N
U4: MAX17048G+T10; SON50P200X200X80-9N

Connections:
3V3: 3V3.TP, C1_BAT2.1, C3.+, C9.1, D7.2 (ANODE), IC1.2 (VDD), IC4.5 (VOUT), J3.2, J4.P4 (VDD), Q2.3 (D), R1.2, R1-PINH1.2, R2-PINH1.2, R5.2, R6.2, R7.2, R8.2, R9.2, R10.2, R_BOOT.1, R_CHANGE.1, R_CL1.1, R_RESET.1, U1.3 (!WP!(IO2)), U1.7 (!HOLD!/!RESET!(IO3)), U1.8 (VCC), U2.2 (3V3), U3.2 (VCC)
32KHZ: R2-PINH1.1, U2.9 (IO1), U3.1 (32KHZ)
DN: D1.4 (I/O2_2), J2.A7, J2.B7
DP: D1.6 (I/O1_2), J2.A6, J2.B6
EPD_3V3: C7.1, EPD_3V3.TP, EPD_C5.2, J1.15, J1.16, L1.2, Q2.2 (S)
EPD_3V3_C: EPD_3V3_C.TP, Q2.1 (G), R_CL1.2, U2.18 (IO20)
EPD_BUSY: EPD_BUSY.TP, J1.9, U2.26 (IO3)
EPD_CS: D6.1, EPD_CS.TP, J1.12, R9.1, U2.11 (IO10)
EPD_DC: EPD_DC.TP, J1.11, U2.5 (IO5)
EPD_RST: EPD_RST.TP, J1.10, U2.21 (IO23)
FLASH_CS: D9.1, R5.1, U1.1 (!CS), U2.12 (IO11)
GDR: J1.2, Q3.1 (G), R4.2
GND: BOOT_BUTTON.1, BOOT_BUTTON.2, C1.2, C1_BAT.2, C1_BAT1.2, C1_BAT2.2, C2.2, C2_BAT.2, C3.-, C4_USB.2, C5.2, C5_USB.2, C6.2, C7.2, C9.2, C10.2, C10_SUPERCAP.1, C11.2, CHANGE_BUTTON.1, CHANGE_BUTTON.2, C_DELAY.2, D1.2 (GND), D3.1 (K), D6.2, D8.2, D9.2, D10.2, D11.2, D12.2, EPD_C1.1, EPD_C2.1, EPD_C5.1, EPD_C6.1, EPD_C7.1, EPD_C7.2, EPD_C8.1, EPD_C9.1, EPD_C10.1, EPD_C11.1, EPD_C12.1, GND.TP, IC1.3 (GND), IC4.2 (VSS), J1.8, J1.17, J1.19, J1.MP1, J1.MP2, J2.A1, J2.A12, J2.B1, J2.B12, J2.MP1, J2.MP2, J2.MP3, J2.MP4, J3.1, J4.G1 (GND_1), J4.G2 (GND_2), J4.G3 (GND_3), J4.G4 (GND_4), J4.P6 (VSS), MCP73831.2 (VSS), R1_PWRUSB.1, R2.1, R2-USB.2, R2-USB1.1, R2_BAT.1, R4.1, RESET_BUTTON.1, RESET_BUTTON.2, SENSOR2.1 (GND), SENSOR2.5 (SDO), SENSOR2.7 (GND), SJ1.1, TP4.TP, U1.4 (GND), U1.9 (EXP), U2.1 (GND), U2.28 (GND), U2.29_1 (GND), U2.29_2 (GND), U2.29_3 (GND), U2.29_4 (GND), U2.29_5 (GND), U2.29_6 (GND), U2.29_7 (GND), U2.29_8 (GND), U2.29_9 (GND), U3.13 (GND), U4.1 (CTG), U4.4 (GND), U4.6 (QSTRT), U4.9 (EP)
GPIO8: R1.1, U2.10 (IO8)
I2C_PW: C1.1, C2.1, R1_PINH.2, R2_PINH.2, SENSOR2.2 (CSB), SENSOR2.6 (VDDIO), SENSOR2.8 (VDD), U2.17 (IO19)
INT_RTC: R1-PINH1.1, TP15.TP, U2.8 (IO0), U3.3 (SQW/!INT)
IO/BOOT: BOOT_BUTTON.3, BOOT_BUTTON.4, C6.1, R_BOOT.2, U2.15 (IO9)
IO/CHANGE: C10.1, CHANGE_BUTTON.3, CHANGE_BUTTON.4, R_CHANGE.2, U2.23 (IO15)
MISO: D12.1, J4.P7 (DAT0), MISO.TP, R8.1, U1.2 (DO(IO1)), U2.27 (IO2)
MOSI: D11.1, J1.14, J4.P3 (CMD), MOSI.TP, R7.1, U1.5 (DI(IO0)), U2.7 (IO7)
unnamed: C1_BAT1.1, D2.1 (CATHODE), IC4.1 (VIN), IC4.3 (CE)
unnamed: C4.1, D3.2 (A), D4.1 (K)
unnamed: J2.A5, R2-USB1.2
unnamed: EPD_C6.2, J1.18
unnamed: CHG_LED.C, R1_BAT.1
unnamed: J2.B5, R2-USB.1
unnamed: MCP73831.1 (STAT), R1_BAT.2
unnamed: MCP73831.5 (PROG), R2_BAT.2
unnamed: EPD_C8.2, J1.20
unnamed: EPD_C2.2, J1.5
unnamed: EPD_C1.2, J1.4
unnamed: C_DELAY.1, IC1.5 (CT)
unnamed: EPD_C10.2, J1.22
unnamed: D7.1 (CATHODE), R_CAPACITOR.1
unnamed: EPD_C12.2, J1.24
PREVGH: D5.1 (K), EPD_C9.2, J1.21
PREVGL: D4.2 (A), EPD_C11.2, J1.23
RESE: J1.3, Q3.2 (S), R3.2
RESE': R2.2, R3.1, SJ1.2
RESET: C5.1, IC1.1 (VOUT), RESET_BUTTON.3, RESET_BUTTON.4, R_RESET.2, U2.3 (EN)
RTC_RST: U2.16 (IO18), U3.4 (!RST)
RX: RX.TP, U2.24 (RXD0/GPIO17)
SCK: D10.1, J1.13, J4.P5 (CLK), R6.1, SCK.TP, U1.6 (CLK), U2.6 (IO6)
SCL: J3.4, R2_PINH.1, SENSOR2.4 (SCK), U2.20 (IO22), U3.16 (SCL), U4.7 (SCL)
SDA: J3.3, R1_PINH.1, SENSOR2.3 (SDI), U2.19 (IO21), U3.15 (SDA), U4.8 (SDA)
SRC: C4.2, D5.2 (A), L1.1, Q3.3 (D)
SS_SD: D8.1, J4.P2 (CD/DAT3), R10.1, U2.4 (IO4)
TX: TX.TP, U2.25 (TXD0/GPIO16)
USB_D+: D1.1 (I/O1_1), U2.14 (IO13)
USB_D-: D1.3 (I/O2_1), U2.13 (IO12)
VBAT: C2_BAT.1, MCP73831.3 (VBAT), Q1.3 (D), TP3.TP, U4.2 (CELL), U4.3 (VDD)
VBUS: C1_BAT.1, C4_USB.1, C5_USB.1, CHG_LED.A, D1.5 (VBUS), D2.2 (ANODE), MCP73831.4 (VIN), PFMF.050.1.2, Q1.1 (G), R1_PWRUSB.2, TP14.TP
VRTC: C10_SUPERCAP.2, C11.1, R_CAPACITOR.2, U3.14 (VBAT)
VUSB: J2.A4, J2.A9, J2.B4, J2.B9, PFMF.050.1.1

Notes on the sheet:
Drawn by: Radu Cosmin
OpenBook Schematic
USB C coonector & ESD protection
LDO Voltage Regulator
SD Card
Display Type Selector
E-Paper Drive Circuit
Li-Po Battery Charging Controller
ESP32 C6
E-Paper Display Header
EPD Power
Environmental Sensor BME688
Voltage Supervisor + Reset & Boot / IO Button
Battery Charge Level
RTC Module DS3231SN
Test Pads
Qwiic / Stemma QT
SPI ESD Protection Lines
NOR Flash

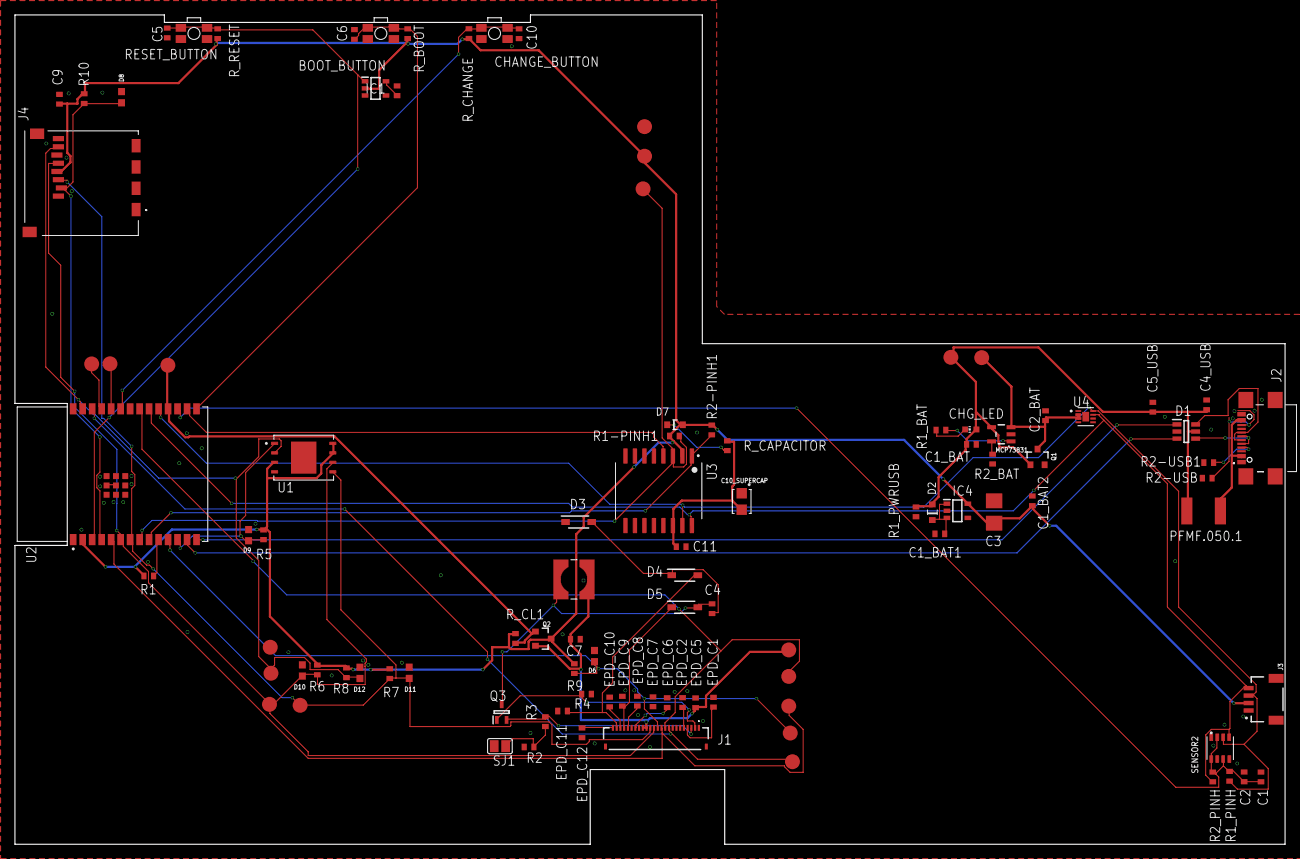
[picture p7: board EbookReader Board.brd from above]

Board: 2 copper layers, 170.0 x 111.0 mm, 103 parts (0 on the bottom side), 54 nets.

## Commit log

2025-03-25 Adaugare a tuturor fisierelor care constituie dispozitivul EbookReader
    [EbookReader Board.brd, EbookReader Schematic.sch]
2025-03-25 Update README.md
    Adaugare 'Bill of Materials'
2025-03-27 Adaugare diagrama de interconectare
2025-03-28 Adaugare model 3D al carcasei si al PCB-ului
2025-03-28 Adaugare mod de utilizare al pinilor ESP32 C6
2025-04-01 Adaugare gerbers.zip
2025-04-02 Adaugare BOM si CPL
    [PnP_EbookReader v27_front.csv]
2025-04-02 Rezolvare extensie pentru BOM
    [BOM.csv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]
2025-04-02 Schimbare BOM varianta succinta in README
2025-04-02 Grupare fisiere
    [BOM.csv, EbookReader Board.brd, EbookReader Schematic.sch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]
2025-04-03 Modificari model 3D dispozitiv si PCB
    [EbookReader Board.brd]
2025-04-13 Incarcare versiuni finale PCB (2D si 3D)
    [EbookReader Board.brd, EbookReader Schematic.sch]
2025-04-13 Restructurare finala fisiere
    [EbookReader 3D PCB.f3d, EbookReader Enclosure.step, EbookReader PCB 3D.step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]
2025-04-13 Adaugare modele noi butoane si rezolvare problema schematic
    [EbookReader PCB 3D.step, EbookReader Schematic.sch, OpenBook Enclosure.step]
2025-04-13 Imbunatatire README.md
    Adaugare surse externe pentru modelele 3D, precum si actualizarea pozei cu noul PCB 3D

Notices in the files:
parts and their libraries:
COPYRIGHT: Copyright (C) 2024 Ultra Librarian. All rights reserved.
